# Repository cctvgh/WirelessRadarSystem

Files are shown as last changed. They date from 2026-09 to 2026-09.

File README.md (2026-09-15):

---
AIGC:
  ContentProducer: '001191110102MAD55U9H0F10002'
  ContentPropagator: '001191110102MAD55U9H0F10002'
  Label: '1'
  ProduceID: 'b8762ebd-76c9-41ca-a2bb-6e1f6f4c271a'
  PropagateID: 'b8762ebd-76c9-41ca-a2bb-6e1f6f4c271a'
  ReservedCode1: '906948f1-5d60-43a9-a1cf-7321b16a049e'
  ReservedCode2: '906948f1-5d60-43a9-a1cf-7321b16a049e'
---

# 无线毫米波雷达智能感知系统 V1.0（Wireless mmWave Radar Smart System）

基于 **24GHz 毫米波雷达（RD-03D）+ ESP32 无线节点**的室内目标感知系统。雷达节点通过 Wi-Fi 将探测目标无线传输至接收端，实现人-雷达-屏幕**零线缆分离部署**，具备警戒区告警、多节点组网、PC Web 可视化、轨迹记录与 CSV 导出等能力，附带**无硬件模拟器**。

> 本仓库是 [Arduino-ESP32-Radarproject](https://github.com/Stevee87/Arduino-ESP32-Radarproject)（MIT License, Copyright (c) 2026 Sudo_solder）的**深度二次开发作品**：在保留原始版权声明的前提下完成代码重构与原创功能增强。

## 功能特性

- **多目标追踪**：RD-03D 雷达最多同时追踪 3 个移动目标，探测距离 8 米、120° 视场
- **多节点组网**：UDP 协议支持最多 8 个雷达节点接入，节点独立分色显示
- **警戒区告警**：矩形警戒区实时判定，目标闯入触发告警（屏幕闪烁 + 蜂鸣 + 事件上报）
- **PC Web 可视化**：零依赖 Python 服务端 + 原生 HTML/Canvas 雷达界面，轨迹回放
- **数据导出**：一键导出 CSV（时间/节点/目标/坐标/速度），支持 Excel 二次分析
- **无硬件演示**：内置数据模拟器，秒级启动全链路演示
- **双端固件**：XIAO ESP32-S3 发射端 + Arduino GIGA R1 触摸屏接收端，随附 3D 打印外壳

## 快速开始（无硬件，1 分钟）

```powershell
cd server
python radar_server.py --simulate --web-port 8081
# 浏览器打开 http://127.0.0.1:8081/
```

有硬件（雷达+ESP32）请阅读 [references/hardware-guide.md](references/hardware-guide.md)。

## 系统架构

```
┌──────────────┐  UART 256000  ┌──────────────────┐  UDP 4210  ┌────────────────────┐
│ RD-03D 雷达  │◄─────────────►│ XIAO ESP32-S3 节点│ ─────────► │ 接收端（二选一）    │
│ 24GHz 多目标 │  帧解析/聚类   │ (发射端固件)      │  无线传输   │ Giga R1 屏显接收端   │
└──────────────┘               └──────────────────┘            │ 或 PC Web 可视化服务 │
                                                                 └────────────────────┘
```

## 目录结构

```
wireless-radar-system/
├── SKILL.md                  # TeleAgent 技能定义
├── LICENSE                   # MIT（含原作者声明）
├── firmware/                 # 双端固件（Arduino）
├── server/                   # PC 服务端 + Web 可视化
├── tools/                    # 无硬件数据模拟器
├── CAD/                      # 3D 打印外壳（4 个 STL）
└── references/               # 部署 / 硬件 / 协议文档
```

## 许可

MIT License — 二次开发声明详见 [LICENSE](LICENSE)。原始项目版权归 Sudo_solder 所有。

## 支持

- 问题反馈：GitHub Issues
- 部署指南：`references/deploy-guide.md`
- 数据协议：`references/protocol.md`

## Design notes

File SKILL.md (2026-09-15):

---
name: wireless-radar-system
description: Deploy and run the Wireless mmWave Radar Smart System - a 24GHz RD-03D mmWave radar (ESP32 wireless node) target sensing system with multi-node networking, alarm zones, PC Web visualization, track recording, CSV export and a no-hardware simulator. Trigger when the user wants to set up, run, or troubleshoot ESP32 radar deployment, millimeter-wave human detection, activity security sensing, or radar data visualization.
name_cn: 无线毫米波雷达智能感知系统
description_cn: 基于RD-03D 24GHz毫米波雷达与ESP32无线节点的目标感知系统，支持多节点组网、警戒区告警、PC Web可视化、轨迹记录与CSV导出，含无硬件模拟器，适用于活动保障安防、智能感知研究与教学演示
AIGC:
  ContentProducer: '001191110102MAD55U9H0F10002'
  ContentPropagator: '001191110102MAD55U9H0F10002'
  Label: '1'
  ProduceID: '391d303b-906a-4549-b1cc-22d6e3efd3d9'
  PropagateID: '391d303b-906a-4549-b1cc-22d6e3efd3d9'
  ReservedCode1: '5a9f9206-22fd-4a40-b052-a54a07ec6523'
  ReservedCode2: '5a9f9206-22fd-4a40-b052-a54a07ec6523'
---

# 无线毫米波雷达智能感知系统（Wireless mmWave Radar Smart System）

基于 **24GHz 毫米波雷达（RD-03D）+ ESP32 无线节点**的室内目标追踪与智能感知系统。雷达节点通过 Wi-Fi 将探测目标无线传输至接收端，实现 **人-雷达-屏幕零线缆分离部署**，并具备警戒区告警、多节点组网、轨迹记录等增强能力。

> 本技能是 [Arduino-ESP32-Radarproject](https://github.com/Stevee87/Arduino-ESP32-Radarproject)（MIT License, Copyright (c) 2026 Sudo_solder）的深度二次开发作品，新增 PC 可视化服务端、多节点组网、警戒告警、模拟器等功能，软著登记为独立开发。

---

## 适用场景

- **活动保障/安防值守**：大型活动现场人员进出探测、警戒区域闯入告警
- **无线感知研究**：毫米波雷达数据处理、多目标追踪算法验证
- **智能家居/办公**：人员存在感知、区域占用统计、自动联动
- **教学演示**：无硬件环境下使用内置模拟器演示雷达扫描界面

## 系统架构

```
┌──────────────┐  UART 256000  ┌──────────────────┐  UDP 4210  ┌────────────────────┐
│ RD-03D 雷达  │◄─────────────►│ XIAO ESP32-S3 节点│◄──────────►│ 接收端（二选一）    │
│ 24GHz 多目标 │  帧解析/聚类   │ (发射端固件)      │  无线传输   │ Giga R1 屏显接收端   │
└──────────────┘               └──────────────────┘            │ 或 PC Web 可视化服务 │
                                                                 └────────────────────┘
```

- **发射端**：XIAO ESP32-S3 读取 RD-03D 雷达帧，目标聚类后经 UDP 无线发送
- **接收端（Giga R1）**：自带触摸屏的移动显示单元，警戒告警 + 蜂鸣提示
- **接收端（PC 服务端）**：纯标准库 Python 服务，Web 可视化 + 轨迹记录 + CSV 导出 + 告警引擎
- **模拟器**：无硬件即可演示完整链路

## 使用方式

### 方式一：无硬件演示（最快上手）

```powershell
# 1. 启动 PC 服务端（内置模拟器）
cd wireless-radar-system\server
python radar_server.py --simulate --web-port 8081

# 2. 浏览器打开
http://127.0.0.1:8081/
```

### 方式二：独立模拟器（联调测试）

```powershell
python radar_server.py --web-port 8081          # 终端 A：启动服务端
python ..\tools\radar_simulator.py --nodes 2    # 终端 B：模拟节点发包
```

### 方式三：真实硬件（双端固件烧录）

1. 按 `references/hardware-guide.md` 准备物料并接线
2. Arduino IDE 打开 `firmware/rd03d_receiver/rd03d_receiver.ino`，烧录至 GIGA R1
   - 依赖库：`Arduino_GigaDisplay_GFX`、`Arduino_GigaDisplayTouch`
3. 打开 `firmware/rd03d_transmitter/rd03d_transmitter.ino`，烧录至 XIAO ESP32-S3
   - 核心库：`WiFi`、`WiFiUdp`（内置）
4. **上电顺序**：先给 GIGA R1 上电，待热点 `RadarNet` 出现后，再给雷达节点上电
5. 若要 PC 端同时查看，将 PC 接入同一热点后运行 `radar_server.py`

## 文件结构

```
wireless-radar-system/
├── SKILL.md                  # 本指南
├── LICENSE                   # MIT（含原作者声明）
├── firmware/
│   ├── rd03d_transmitter/    # 雷达节点发射端固件（ESP32-S3）
│   └── rd03d_receiver/       # 显示接收端固件（Giga R1）
├── server/
│   ├── radar_server.py       # PC 服务端（UDP+Web，纯标准库）
│   └── index.html            # Web 雷达可视化界面
├── tools/
│   └── radar_simulator.py    # 无硬件数据模拟器
└── references/
    ├── deploy-guide.md       # 部署指南（含 BAT 一键脚本）
    ├── hardware-guide.md     # 物料清单与接线图
    └── protocol.md           # RD-03D 数据协议与 UDP 报文格式
```

## 已知限制

- RD-03D 为多普勒雷达，仅能探测**移动目标**，静止站立人员不产生回波
- 24GHz 信号可穿透薄门/墙但探测距离显著衰减
- 默认 WiFi 凭据（`RadarNet`/`radar12345`）为局域网演示配置，正式部署请修改固件中的 `WIFI_SSID`/`WIFI_PASSWORD`
- GIGA R1 与雷达节点上电顺序有要求：先接收端后节点

## 协议与合规

- 本系统二次开发自 MIT 开源项目，保留原始版权声明，可自由使用、修改与分发
- 雷达模块按所在地区无线电管理要求使用（RD-03D 已取得 CE 认证）
- 本项目不含任何遥测、数据外传与后门代码（安全扫描零高风险项）

## 版本

- V1.0（2026-09）：首个正式版本，含双端固件、PC 可视化服务端、模拟器

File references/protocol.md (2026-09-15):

---
AIGC:
  ContentProducer: '001191110102MAD55U9H0F10002'
  ContentPropagator: '001191110102MAD55U9H0F10002'
  Label: '1'
  ProduceID: 'fb770e5b-8f00-4d1e-bbb1-88ac91fa3b59'
  PropagateID: 'fb770e5b-8f00-4d1e-bbb1-88ac91fa3b59'
  ReservedCode1: 'ccf5ac3a-8de8-4e19-a242-96e7e08e9d3e'
  ReservedCode2: 'ccf5ac3a-8de8-4e19-a242-96e7e08e9d3e'
---

# RD-03D 数据协议与 UDP 封包格式

本文件定义无线毫米波雷达智能感知系统 V1.0 的完整数据链路协议，供二次开发与排障参考。

## 1. RD-03D 雷达串口协议

RD-03D（Ai-Thinker，24GHz FMCW/多普勒毫米波雷达）通过 UART 输出目标数据帧，波特率 **256000**。

### 1.1 数据帧结构

| 段 | 长度 | 说明 |
|----|---|---|
| 帧头 | 4 字节 | `AA FF 03 00` |
| 载荷 | 26 字节 | 3 组目标数据（每组 8 字节）+ 2 字节尾校验 |
| 帧尾 | 2 字节 | `55 CC` |

### 1.2 单目标数据（8 字节）

| 偏移 | 长度 | 字段 | 说明 |
|---|---|---|---|
| 0-1 | 2B | X | 横向坐标（毫米），有符号 16 位补码 |
| 2-3 | 2B | Y | 纵向距离（毫米），有符号 16 位补码 |
| 4-5 | 2B | SPD | 速度（毫米/秒），有符号 |
| 6-7 | 2B | 预留 | 恒为 0 |

**空目标**：8 字节全零表示该目标槽无有效数据。

**解码规则**（与固件 `decodeSigned` 一致）：

```
raw = lo | (hi << 8)
value = raw & 0x8000 ? (int16_t)(raw | 0xFFFF0000) : (int16_t)raw   # 补码符号扩展
```

**坐标说明**：X 为水平偏移（左负右正），Y 为径向距离（正前方）。距离过滤：仅接受 **100mm < 距离 ≤ 8000mm** 的有效目标。

### 1.3 指令帧（配置雷达）

| 指令 | 内容 | 用途 |
|---|---|---|
| 启用 | `FD FC FB FA 04 00 FF 00 01 00 04 03 02 01` | 启用雷达 |
| 多目标 | `FD FC FB FA 02 00 90 00 04 03 02 01` | 进入多目标模式 |
| 结束 | `FD FC FB FA 02 00 FE 00 04 03 02 01` | 结束指令序列 |

发射端固件在启动时依次下发三条指令，此后每 60 秒重复下发一次，防止雷达退出多目标模式。

## 2. UDP 无线传输协议

### 2.1 网络拓扑

```
发射节点 (XIAO ESP32-S3)  ——WiFi客户端——►  接收端热点 (AP)
   UDP 发送端口 = 4210          ◄——网关 IP 推断——  SSID: RadarNet
                                  密码: radar12345
```

发射端作为 STA 连接接收端建立的 AP 热点，**接收端 IP 通过 DHCP 网关地址自动获取**（`WiFi.gatewayIP()`）。

### 2.2 数据包（41 字节, packed, little-endian）

```
偏移    类型      字段          说明
0      uint32    magic         协议魔数 0x0D03DA7A（校验用）
4      uint32    nodeId        节点编号（1 起，多节点组网区分）
8      uint32    frameCount    帧计数
12     uint32    uptimeMs      节点运行毫秒
16     int16     t0.x          目标0 X
18     int16     t0.y          目标0 Y
20     int16     t0.spd        目标0 速度
22     uint8     t0.valid      目标0 有效标记
23     int16     t1.x          目标1 X
25     int16     t1.y          目标1 Y
27     int16     t1.spd        目标1 速度
29     uint8     t1.valid      目标1 有效标记
30     int16     t2.x          目标2 X
32     int16     t2.y          目标2 Y
34     int16     t2.spd        目标2 速度
36     uint8     t2.valid      目标2 有效标记
37     uint8     flags         状态位（bit0=节点在线）
38-40  uint8[3]  reserved      预留
```

Python 端解包模板（与 `radar_server.py` 一致）：

```python
PACKET_FMT = "<IIIIhhhBhhhBhhhBB3s"
```

### 2.3 心跳机制

发射端在超过 2 秒无目标数据时发送 **心跳包**（目标全零、`flags=0x01`），使接收端能持续感知节点在线状态。接收端超过 3 秒未收到任何数据包即判定节点离线。

## 3. 警戒区判定

警戒区为雷达坐标系中的矩形区域（毫米）：

```
X ∈ [-4000, 4000]    （横向）
Y ∈ [200, 4000]     （纵向：200mm 起避免贴脸误报）
```

任一台法目标落入矩形即触发警戒告警；目标全部离开后告警复位。判定逻辑在 Giga 固件与 PC 服务端中一致实现，事件以 JSON 上报：

```json
{"event":"alarm_enter","node":1}
{"event":"alarm_exit","node":1}
{"event":"node_lost","node":2}
```

## 4. 自定义扩展指引

- 新增传感器类型：在 `Target` 结构后扩展字段，同步更新两端 `struct` 定义与大小校验
- 调整警戒区：修改 `ALARM_ZONE_*` 宏（固件）与 `ALARM_ZONE_*` 常量（server.py）
- 修改组网凭据：修改 `WIFI_SSID`/`WIFI_PASSWORD`（两端固件），并保持一致

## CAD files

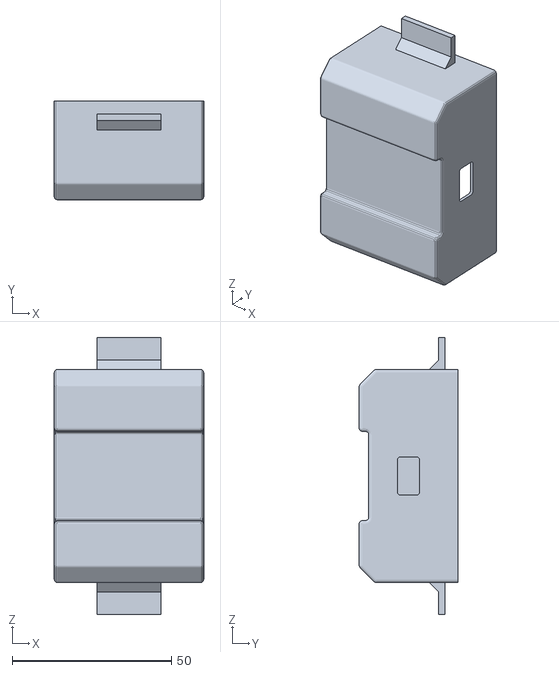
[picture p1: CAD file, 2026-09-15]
CAD/top radarmodule.stl
47.0 x 31.0 x 87.0

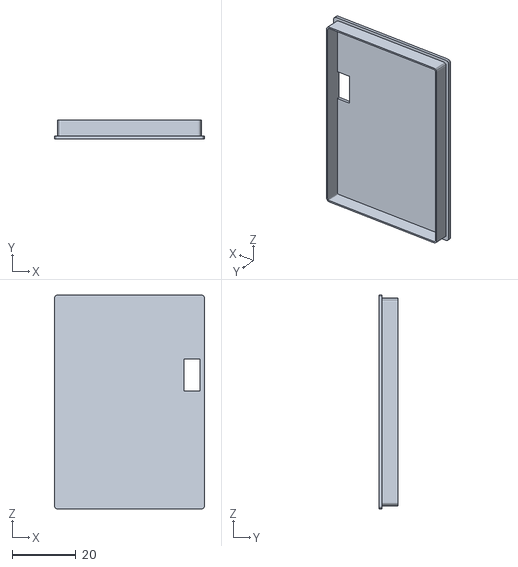
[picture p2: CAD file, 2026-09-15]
CAD/bottom radarmodule.stl
47.0 x 6.00 x 67.0

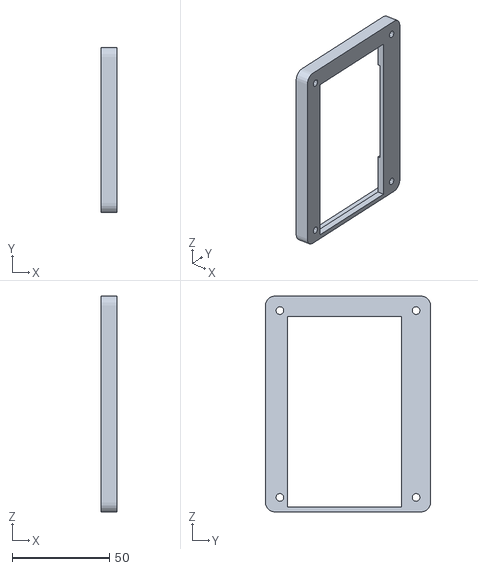
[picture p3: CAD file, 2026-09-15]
CAD/top display.stl
8.00 x 85.0 x 111.0

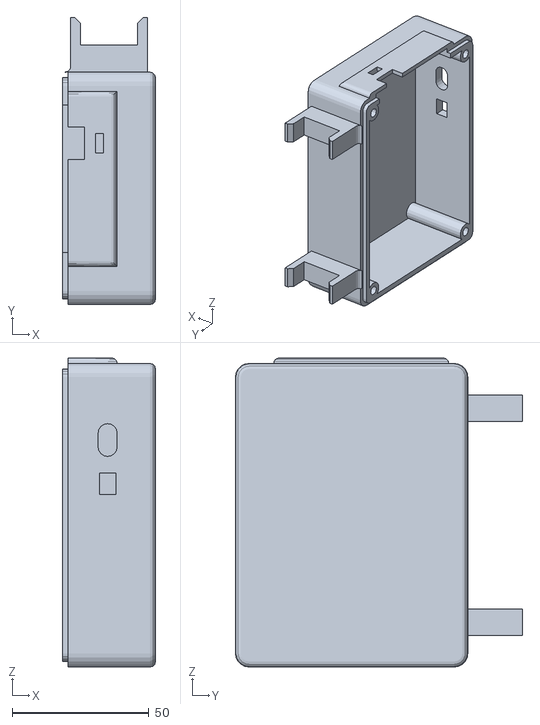
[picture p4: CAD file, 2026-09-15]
CAD/body display.stl
34.0 x 105.0 x 113.0

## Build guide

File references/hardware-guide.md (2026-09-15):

---
AIGC:
  ContentProducer: '001191110102MAD55U9H0F10002'
  ContentPropagator: '001191110102MAD55U9H0F10002'
  Label: '1'
  ProduceID: '7a103c28-e777-4f04-b889-d0c2404a3aee'
  PropagateID: '7a103c28-e777-4f04-b889-d0c2404a3aee'
  ReservedCode1: '4de7e3fe-066c-43c6-97f3-1e9d7269c627'
  ReservedCode2: '4de7e3fe-066c-43c6-97f3-1e9d7269c627'
---

# 硬件物料清单与接线指南

本文档为无线毫米波雷达智能感知系统 V1.0 的完整硬件部署说明。系统分为两个节点：

- **雷达节点（发射端）**：XIAO ESP32-S3 + RD-03D 雷达，电池供电，无线发射目标数据
- **显示节点（接收端）**：Arduino GIGA R1 + 显示扩展板，或 PC 运行服务端

## 1. 物料清单

### 雷达节点（发射端）

| 数量 | 物料 | 说明 |
|---|---|---|
| 1 | Seeed Studio XIAO ESP32-S3 | 主控，WiFi/BLE 双模 |
| 1 | RD-03D 雷达模块（安信可） | 24GHz 毫米波，3 目标，8m 探测 |
| 1 | 3.7V 锂聚合物电池 602560（约 1300mAh） | 雷达侧供电 |
| 1 | 拨动开关 | 电源开关 |
| 1 | MT3608 升压模块 | 3.7V → 5V 供雷达 |
| 若干 | 杜邦线/焊接线 | 连接线 |

> 雷达节点可直接用 XIAO 的 USB-C 充电，无需额外充电板。

### 显示节点（接收端，Giga R1 方案）

| 数量 | 物料 | 说明 |
|---|---|---|
| 1 | Arduino GIGA R1 | 主控，自带 WiFi（R4 无线模组） |
| 1 | GIGA Display Shield | 3.97 寸触摸屏 800x480 |
| 1 | 3.7V 锂电 1160100 ≥ 5000mAh | 显示侧供电 |
| 1 | 开关 | 电源开关 |
| 1 | MT3608 升压模块 | 3.7V → 6V 供 GIGA VIN |
| 1 | BW4056 USB-C 充电板 | 显示侧充电 |
| 1 | 无源压电蜂鸣器模块 | 距离感知/告警提示音 |
| 1 | Mini 电量指示板（1S Li-ion） | 电池电量显示（可选） |

## 2. 接线说明

### 2.1 雷达节点接线（XIAO ESP32-S3 ↔ RD-03D）

| RD-03D | XIAO ESP32-S3 | 说明 |
|---|---|---|
| TX | D0（GPIO1） | UART1 RX（波特率 256000） |
| RX | D1（GPIO2） | UART1 TX |
| VCC | 5V | 由升压模块供电 |
| GND | GND | 共地 |

> **警告**：不要使用 D6/D7（GPIO43/44），它们被 USB-Serial（UART0）占用。

雷达节点供电链路：`锂电池 → 开关 → MT3608(5V) → XIAO 5V 与雷达 VCC`。

### 2.2 显示节点供电

Giga R1 侧：`LiPo(5000mAh) → 开关 → 升压(6V) → GIGA VIN`。

### 2.3 蜂鸣器接线（显示节点）

| 蜂鸣器 | GIGA R1 |
|---|---|
| VCC | 5V |
| Signal | D9 |
| GND | GND |

> 必须使用 **无源** 压电蜂鸣器。有源蜂鸣器自带振荡器，无法响应固件发送的频率参数。

### 2.4 网络参数（默认值）

| 参数 | 值 |
|---|-----|
| AP SSID | `RadarNet` |
| AP 密码 | `radar12345` |
| UDP 端口 | `4210` |
| GIGA IP | `192.168.4.1`（AP 网关） |

## 3. 固件烧录

### 3.1 安装 Arduino IDE 依赖

**显示节点（Giga R1）**：
1. 开发板管理器安装 `Arduino Mbed OS GIGA Boards`
2. 库管理器安装 `Arduino_GigaDisplay_GFX`、`Arduino_GigaDisplayTouch`

**雷达节点（XIAO ESP32-S3）**：
1. 开发板管理器安装 `esp32`（Espressif）
2. 选择板型 `XIAO ESP32-S3`（Seeed 支持包）

### 3.2 烧录步骤

```
1. 打开 firmware/rd03d_receiver/rd03d_receiver.ino，烧录到 GIGA R1
2. 打开 firmware/rd03d_transmitter/rd03d_transmitter.ino，烧录到 XIAO ESP32-S3
3. 若 XIAO 为全新板，需先按住 BOOT 键插入 USB 进入下载模式
```

### 3.3 上电顺序（关键）

1. **先给 GIGA R1 上电**，等待热点 `RadarNet` 出现（约 8 秒）
2. 再给雷达节点上电，节点自动连接热点并开始上报

> 顺序颠倒会导致 Wi-Fi 连接失败，需重启节点。

## 4. 3D 打印外壳

原项目提供 4 个 STL 文件（位于原始仓库 `CAD files/`，本技能发布包已包含）：

| 文件 | 尺寸 (W×D×H) | 用途 |
|---|---|---|
| `body display.stl` | 31 × 83 × 109 mm | 显示端机身 |
| `top display.stl` | — | 显示端顶盖 |
| `bottom radarmodule.stl` | 29 × 67 × 30 mm | 雷达端底壳 |
| `top radarmodule.stl` | 29 × 64 × 27 mm | 雷达端顶盖 |

## 5. 安全注意事项

- 锂电池接线务必核对极性，充电时关闭电源开关，充电过程有人值守
- 24GHz 频段按所在地无线电管理要求使用（RD-03D 已取得 CE 认证）
- 雷达可穿透薄墙/门探测运动目标，部署时注意隐私边界
- 本项目按 MIT 许可提供，无任何明示或默示担保，风险自担

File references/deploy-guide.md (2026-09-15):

---
AIGC:
  ContentProducer: '001191110102MAD55U9H0F10002'
  ContentPropagator: '001191110102MAD55U9H0F10002'
  Label: '1'
  ProduceID: '3113197a-09b9-4b55-b35b-a33c7c303491'
  PropagateID: '3113197a-09b9-4b55-b35b-a33c7c303491'
  ReservedCode1: 'ce95500b-d343-4c40-bd1f-807c65dc4cb3'
  ReservedCode2: 'ce95500b-d343-4c40-bd1f-807c65dc4cb3'
---

# 部署指南

本文档覆盖三种部署形态：**纯 PC 演示**（无硬件）、**硬件双节点**、**PC 接收端与硬件共存**，并提供一键启动脚本。

## 1. 环境要求

| 项 | 要求 |
|----|---|
| Python | 3.8+（Windows/Linux/macOS 均可） |
| 依赖 | **零第三方依赖**（仅标准库） |
| 浏览器 | Chrome / Edge / Firefox（支持 Canvas 与 Fetch） |
| 硬件（可选） | XIAO ESP32-S3 + RD-03D、Arduino GIGA R1（需烧录固件） |

> 无 Python 环境时也可直接双击 `server/index.html` 查看界面，但无实时数据。

## 2. 方式一：纯 PC 演示（无需任何硬件）

### 2.1 启动服务端（内置模拟器）

```powershell
cd wireless-radar-system\server
python radar_server.py --simulate --web-port 8081
```

启动后终端显示：

```
============================================================
 无线毫米波雷达智能感知系统 V1.0 - PC 服务端
============================================================
 UDP 监听端口 : 4210
 Web 界面     : http://127.0.0.1:8081/
```

### 2.2 访问可视化界面

浏览器打开 `http://127.0.0.1:8081/`，可看到：

- 雷达扫描动画、120° 视场、距离圈（0.5m–8m）
- 2 个模拟节点、4 个运动目标及轨迹
- 警戒区（黄色虚线矩形）与目标闯入告警（红色横幅 + 蜂鸣）
- 节点状态、目标数、帧率实时统计
- 「导出 CSV」下载全部轨迹数据

## 3. 方式二：有硬件双节点部署

### 3.1 烧录固件

按 `references/hardware-guide.md` 完成接线与烧录。

### 3.2 上电

1. 先给 GIGA R1（接收端）上电，等待热点 `RadarNet` 出现
2. 再给 XIAO ESP32-S3（雷达节点）上电，节点自动连接并上报
3. GIGA 触摸屏显示雷达界面，默认蜂鸣器开启，点击「BUZZER AN」静音

### 3.3 可选：PC 接收

若希望 PC 端同时接收与记录，将 PC 接入同一 WiFi（`RadarNet`），然后：

```powershell
python radar_server.py --web-port 8081
```

PC 通过热点直接接收节点 UDP 数据（默认端口 4210）。

## 4. 方式三：独立模拟器联调

终端 A（服务端）与终端 B（模拟器）分开运行：

```powershell
# 终端 A
python radar_server.py --web-port 8081

# 终端 B
python ..\tools\radar_simulator.py --host 127.0.0.1 --port 4210 --nodes 2 --targets 3
```

模拟器参数：

| 参数 | 默认 | 说明 |
|---|---|---|
| `--host` | 127.0.0.1 | 服务端 IP |
| `--port` | 4210 | UDP 端口 |
| `--nodes` | 2 | 模拟节点数（1-8） |
| `--targets` | 2 | 每节点活动目标数 |
| `--fps` | 10 | 发送帧率 |

## 5. 一键启动脚本（Windows）

创建 `启动雷达演示.bat`（UTF-8 编码）到项目根目录：

```bat
@echo off
chcp 65001 >nul
title 无线毫米波雷达智能感知系统
cd /d "%~dp0server"
start "radar-server" python radar_server.py --simulate --web-port 8081
timeout /t 5 >nul
start "" "http://127.0.0.1:8081/"
echo 雷达演示已启动，浏览器自动打开...
pause
```

停止脚本 `停止雷达.bat`：

```bat
@echo off
taskkill /IM python.exe /FI "WINDOWTITLE eq radar-server" /T /F >nul 2>&1
echo 已停止
pause
```

## 6. 常见问题

| 现象 | 排查 |
|---|---|
| Web 页面打不开 | 确认服务端已启动；检查端口是否被占用（`netstat -ano | findstr 8081`） |
| 界面无目标数据 | 确认模拟器/节点已发送数据；检查 UDP 端口一致 |
| 节点状态一直「离线」 | 检查节点 WiFi 连接、热点 SSID/密码、上电顺序 |
| 告警不触发 | 确认警戒区参数与目标坐标；模拟目标是否进入 `Y≥200` 区域 |
| 8080 被占用 | 加 `--web-port` 改用其他端口（如 8081） |

## 7. 数据导出

「导出CSV」生成文件包含列：

```
ts,node,target,x_mm,y_mm,speed_mm_s,distance_mm
```

可用于 Excel 二次分析（进入/离开次数、逗留时长、热力统计）。

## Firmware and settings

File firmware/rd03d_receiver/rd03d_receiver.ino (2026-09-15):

/*
 * ============================================================================
 *  无线毫米波雷达智能感知系统 V1.0 —— 雷达显示接收端固件（Arduino Giga R1）
 *  Wireless mmWave Radar Smart System - Radar Display Receiver Firmware
 * ============================================================================
 *  硬件平台  : Arduino GIGA R1 + GIGA Display Shield（800x480 触摸屏）
 *  功能概述  :
 *    1. 建立 WiFi 热点（默认 SSID=RadarNet），供雷达节点接入
 *    2. UDP 接收多节点雷达数据（协议魔数校验，按 nodeId 区分节点）
 *    3. 雷达扫描界面实时渲染：扇形扫描、距离圈、目标点（多节点分色）
 *    4. 目标"幽灵"过滤：2 秒无真实位移的目标自动隐藏，抑制静止杂波
 *    5. 警戒区域告警：目标进入配置的警戒区触发报警（蜂鸣器+屏显+串口事件）
 *    6. 距离感知蜂鸣：无源压电蜂鸣器按最近目标距离缩放节拍与音调
 *    7. 触摸静音按钮：一键关闭蜂鸣器，不影响雷达可视化
 *    8. 连接状态看门狗：节点失联自动清理显示并提示
 *  网络参数  : AP SSID=RadarNet / 密码=radar12345 / UDP 端口=4210 / 自身 IP=192.168.4.1
 *  蜂鸣器    : 无源压电蜂鸣器 VCC=5V / Signal=D9 / GND=GND
 *  参考来源  : Arduino-ESP32-Radarproject (MIT License, Copyright (c) 2026 Sudo_solder)
 *              本固件在 MIT 许可下深度重构并增强功能。
 * ============================================================================
 *  MIT License - 详见项目根目录 LICENSE
 * ============================================================================
 */

#include <WiFi.h>
#include <WiFiUDP.h>
#include "Arduino_GigaDisplay_GFX.h"
#include "Arduino_GigaDisplayTouch.h"

/* ============================ 集中配置区 ============================ */

// ---- 网络配置（热点）----
#define AP_SSID        "RadarNet"        // 热点名称
#define AP_PASS        "radar12345"     // 热点密码
#define UDP_PORT       4210             // UDP 监听端口
#define MAX_NODES      4                // 最大支持节点数（多节点组网）

// ---- 显示与雷达 ----
#define SCREEN_W       800
#define SCREEN_H       480
#define RADAR_CX       400
#define RADAR_CY       480
#define RADAR_R        440
#define MAX_DIST_MM    8000.0f
#define SECTOR_HALF    60.0f
#define MAX_TARGETS    3               // 单节点最多 3 目标
#define MOVE_THRESH_MM 15.0f           // 目标位移判定阈值（毫米）

// ---- 警戒区配置（雷达坐标系，单位毫米）----
#define ALARM_ZONE_MIN_X  -4000        // 警戒区 X 下限
#define ALARM_ZONE_MAX_X   4000        // 警戒区 X 上限
#define ALARM_ZONE_MIN_Y  200          // 警戒区 Y 下限（近处）
#define ALARM_ZONE_MAX_Y  4000         // 警戒区 Y 上限（远处）

// ---- 蜂鸣器 ----
#define BUZZER_PIN       9             // 无源蜂鸣器信号引脚
#define BEEP_DUR_MS      70            // 单个蜂鸣时长
#define BEEP_DIST_MIN    300.0f        // 最近距离（毫米）
#define BEEP_DIST_MAX    8000.0f       // 最远距离（毫米）
#define BEEP_INTERVAL_MIN  120         // 最近蜂鸣间隔（毫秒）
#define BEEP_INTERVAL_MAX  900         // 最远蜂鸣间隔（毫秒）
#define BEEP_FREQ_MIN      700         // 最远音调（Hz）
#define BEEP_FREQ_MAX      1800        // 最近音调（Hz）
#define ALARM_FREQ         2200        // 警戒告警音调（Hz）
#define ALARM_INTERVAL_MS  250         // 警戒告警间隔（毫秒）

// ---- 静音按钮 ----
#define BTN_X 671
#define BTN_Y 80
#define BTN_W 128
#define BTN_H 40

// ---- 连接看门狗 ----
#define LINK_TIMEOUT_MS     3000        // 节点失联判定时间
#define BG_REFRESH_INTERVAL_MS 10000    // 全屏刷新周期（消除残影）
#define STILL_TIMEOUT_MS    2000        // 幽灵目标静止隐藏时间

/* ============================ 数据结构 ============================ */

// 单目标
struct Target {
  int16_t x;        // X 坐标（毫米）
  int16_t y;        // Y 坐标（毫米）
  int16_t spd;      // 速度（毫米/秒）
  uint8_t valid;    // 有效性
};

// 网络数据包（与发射端保持一致）
struct __attribute__((packed)) UdpPacket {
  uint32_t magic;       // 协议魔数 0xD03DA7A
  uint32_t nodeId;      // 节点编号
  uint32_t frameCount;  // 帧计数
  uint32_t uptimeMs;    // 节点运行时间
  Target   targets[MAX_TARGETS];
  uint8_t  flags;       // 状态位
  uint8_t  reserved[3];
};

// 显示目标
struct DisplayTarget {
  float x, y, spd;
  bool  valid;
  bool  inAlarmZone;    // 是否处于警戒区
};

// 节点状态
struct NodeState {
  bool     online;
  uint32_t lastPacketMs;
  uint32_t lastFrame;
  uint32_t nodeId;
};

// 目标点渲染状态
struct DotState {
  int16_t cx, cy, bx, by, bw, bh;
  bool active;
};

/* ============================ 全局变量 ============================ */

GigaDisplay_GFX          display;
Arduino_GigaDisplayTouch touch;
WiFiUDP                  udp;

NodeState     nodes[MAX_NODES];
DisplayTarget targets[MAX_NODES][MAX_TARGETS];
DisplayTarget lastDrawn[MAX_NODES][MAX_TARGETS];
DotState      dots[MAX_NODES][MAX_TARGETS];
DisplayTarget prevRaw[MAX_NODES][MAX_TARGETS];      // 幽灵过滤基准
uint32_t      stillSinceMs[MAX_NODES][MAX_TARGETS];
bool          staleNow[MAX_NODES][MAX_TARGETS];

uint32_t frameCountGlobal = 0;
bool     alarmActive      = false;   // 当前帧是否处于警戒告警
bool     alarmWasActive   = false;   // 上一帧警戒状态（用于事件沿触发）
bool     buzzerMuted      = false;

uint32_t lastBeepMs   = 0;
bool     beepActive   = false;
uint32_t beepStartMs  = 0;

bool     touchDownLast = false;
uint32_t lastToggleMs  = 0;

uint32_t lastBgRefreshMs = 0;
uint32_t lastUptimeMs    = 0;

/* ============================ 颜色定义 ============================ */

#define C_BG     0x0000
#define C_GREEN  0x07E0
#define C_GDIM   0x02E0
#define C_RED    0xF800
#define C_AMBER  0xFD20
#define C_CYAN   0x07FF
#define C_WHITE  0xFFFF
#define C_ORANGE 0xFBE0

// 节点颜色（最多 4 节点）
static const uint16_t NODE_COLS[4] = {C_RED, C_AMBER, C_CYAN, C_ORANGE};

/* ============================ 函数声明 ============================ */

bool inAlarmZone(float x, float y);

/* ============================ UDP 接收 ============================ */

/**
 * @brief 接收并解析节点 UDP 数据包
 *        校验魔数后按 nodeId 路由到对应节点的状态槽，更新目标数据
 */
void receiveUdp() {
  int sz = udp.parsePacket();
  if (sz < (int)sizeof(UdpPacket)) return;

  UdpPacket pkt;
  udp.read((uint8_t*)&pkt, sizeof(pkt));

  // 协议魔数校验
  if (pkt.magic != 0xD03DA7A) return;

  // 节点索引（nodeId 从 1 开始）
  int idx = (int)(pkt.nodeId - 1);
  if (idx < 0 || idx >= MAX_NODES) idx = 0;

  nodes[idx].online       = true;
  nodes[idx].lastPacketMs = millis();
  nodes[idx].lastFrame    = pkt.frameCount;
  nodes[idx].nodeId       = pkt.nodeId;

  frameCountGlobal = pkt.frameCount;

  // 更新目标数据
  for (int t = 0; t < MAX_TARGETS; t++) {
    if (pkt.targets[t].valid) {
      targets[idx][t].x     = (float)pkt.targets[t].x;
      targets[idx][t].y     = (float)pkt.targets[t].y;
      targets[idx][t].spd   = (float)abs(pkt.targets[t].spd);
      targets[idx][t].valid = true;
      targets[idx][t].inAlarmZone = inAlarmZone((float)pkt.targets[t].x, (float)pkt.targets[t].y);
    } else {
      targets[idx][t].valid = false;
    }
  }
}

/**
 * @brief 警戒区判定：目标坐标是否落入警戒矩形
 */
bool inAlarmZone(float x, float y) {
  return (x >= ALARM_ZONE_MIN_X && x <= ALARM_ZONE_MAX_X &&
          y >= ALARM_ZONE_MIN_Y && y <= ALARM_ZONE_MAX_Y);
}

/* ============================ 坐标变换与背景 ============================ */

/**
 * @brief 距离到像素半径的非线性映射（近处放大、远处压缩）
 */
float distToR(float d) {
  if (d <= 0)       return 0;
  if (d <= 2000.0f) return (d / 2000.0f) * 0.50f * RADAR_R;
  if (d <= 4000.0f) return (0.50f + (d - 2000.0f) / 2000.0f * 0.25f) * RADAR_R;
  if (d <= 6000.0f) return (0.75f + (d - 4000.0f) / 2000.0f * 0.15f) * RADAR_R;
  return (0.90f + (d - 6000.0f) / 2000.0f * 0.10f) * RADAR_R;
}

void targetToPixel(float x, float y, int16_t &px, int16_t &py) {
  float dist  = sqrtf(x * x + y * y);
  float angle = atan2f(x, y) * 180.0f / PI;
  float r     = distToR(dist);
  float rad   = (angle - 90.0f) * PI / 180.0f;
  px = RADAR_CX + (int16_t)(r * cosf(rad));
  py = RADAR_CY + (int16_t)(r * sinf(rad));
}

/**
 * @brief 在雷达界面上绘制警戒区轮廓（黄色矩形 + ZONE 标注）
 */
void drawAlarmZoneOutline() {
  int16_t x1, y1, x2, y2;
  targetToPixel(ALARM_ZONE_MIN_X, ALARM_ZONE_MIN_Y, x1, y1);
  targetToPixel(ALARM_ZONE_MAX_X, ALARM_ZONE_MAX_Y, x2, y2);
  display.drawRect(min(x1, x2), min(y1, y2), abs(x2 - x1), abs(y2 - y1), C_AMBER);
  display.setTextColor(C_AMBER); display.setTextSize(1);
  display.setCursor(min(x1, x2) + 2, min(y1, y2) + 2);
  display.print("ZONE");
}

/**
 * @brief 重绘指定矩形区域内的背景（用于目标点擦除，避免整体闪烁）
 */
void redrawBg(int16_t rx1, int16_t ry1, int16_t rw, int16_t rh) {
  int16_t rx2 = rx1 + rw - 1, ry2 = ry1 + rh - 1;
  if (rx1 < 0) rx1 = 0; if (ry1 < 0) ry1 = 0;
  if (rx2 >= SCREEN_W) rx2 = SCREEN_W - 1;
  if (ry2 >= SCREEN_H) ry2 = SCREEN_H - 1;
  if (rx1 > rx2 || ry1 > ry2) return;
  display.fillRect(rx1, ry1, rx2 - rx1 + 1, ry2 - ry1 + 1, C_BG);

  // 扇形扫描网格（单传感器 120° 视场，居中于 0°）
  float c = 0.0f;
  for (float a = c - SECTOR_HALF; a <= c + SECTOR_HALF; a += 0.6f) {
    float rad = (a - 90.0f) * PI / 180.0f;
    for (float r = 0; r <= RADAR_R; r += 1.5f) {
      int16_t px = RADAR_CX + (int16_t)(r * cosf(rad));
      int16_t py = RADAR_CY + (int16_t)(r * sinf(rad));
      if (px >= rx1 && px <= rx2 && py >= ry1 && py <= ry2) display.drawPixel(px, py, 0x0180);
    }
  }

  // 距离圈（0.5m~8m）
  float rd[] = {500, 1000, 2000, 3000, 4000, 5000, 6000, 7000, 8000};
  uint16_t rc[] = {0x00C0, C_GREEN, 0x00C0, 0x00C0, C_GDIM, 0x00C0, 0x00C0, 0x00C0, C_GREEN};
  for (int ri = 0; ri < 9; ri++) {
    float r = distToR(rd[ri]);
    for (float a = c - SECTOR_HALF; a <= c + SECTOR_HALF; a += 0.5f) {
      float rad = (a - 90.0f) * PI / 180.0f;
      int16_t px = RADAR_CX + (int16_t)(r * cosf(rad));
      int16_t py = RADAR_CY + (int16_t)(r * sinf(rad));
      if (px >= rx1 && px <= rx2 && py >= ry1 && py <= ry2) display.drawPixel(px, py, rc[ri]);
    }
  }

  // 角度线
  int degs[] = {-60, -30, 0, 30, 60};
  for (int i = 0; i < 5; i++) {
    float rad = (c + degs[i] - 90.0f) * PI / 180.0f;
    for (float r = 0; r <= RADAR_R; r += 1.5f) {
      int16_t px = RADAR_CX + (int16_t)(r * cosf(rad));
      int16_t py = RADAR_CY + (int16_t)(r * sinf(rad));
      if (px >= rx1 && px <= rx2 && py >= ry1 && py <= ry2)
        display.drawPixel(px, py, degs[i] == 0 ? C_GDIM : 0x0200);
    }
  }

  // 警戒区轮廓
  drawAlarmZoneOutline();

  // 雷达原点
  if (RADAR_CX >= rx1 && RADAR_CX <= rx2 && RADAR_CY >= ry1 && RADAR_CY <= ry2) {
    display.fillCircle(RADAR_CX, RADAR_CY, 5, C_GREEN);
    display.drawCircle(RADAR_CX, RADAR_CY, 9, C_GDIM);
  }
}

/**
 * @brief 全屏绘制雷达背景
 */
void drawBackground() {
  display.fillScreen(C_BG);
  float c = 0.0f;

  // 扇形网格
  for (float a = c - SECTOR_HALF; a <= c + SECTOR_HALF; a += 0.6f) {
    float rad = (a - 90.0f) * PI / 180.0f;
    for (float r = 0; r <= RADAR_R; r += 1.5f) {
      int16_t px = RADAR_CX + (int16_t)(r * cosf(rad));
      int16_t py = RADAR_CY + (int16_t)(r * sinf(rad));
      if (px >= 0 && px < SCREEN_W && py >= 0 && py < SCREEN_H) display.drawPixel(px, py, 0x0180);
    }
  }

  // 距离圈与标注
  float rd[] = {500, 1000, 2000, 3000, 4000, 5000, 6000, 7000, 8000};
  uint16_t rc[] = {0x00C0, C_GREEN, 0x00C0, 0x00C0, C_GDIM, 0x00C0, 0x00C0, 0x00C0, C_GREEN};
  for (int ri = 0; ri < 9; ri++) {
    float r = distToR(rd[ri]);
    for (float a = c - SECTOR_HALF; a <= c + SECTOR_HALF; a += 0.5f) {
      float rad = (a - 90.0f) * PI / 180.0f;
      int16_t px = RADAR_CX + (int16_t)(r * cosf(rad));
      int16_t py = RADAR_CY + (int16_t)(r * sinf(rad));
      if (px >= 0 && px < SCREEN_W && py >= 0 && py < SCREEN_H) display.drawPixel(px, py, rc[ri]);
    }
    display.setTextColor(ri == 1 || ri == 8 ? C_GREEN : 0x0380); display.setTextSize(1);
    char buf[8];
    if (rd[ri] < 1000) sprintf(buf, "0.5m"); else sprintf(buf, "%.0fm", rd[ri] / 1000.0f);
    float rR = (c + SECTOR_HALF - 90.0f) * PI / 180.0f;
    int16_t lx = RADAR_CX + (int16_t)((r + 4) * cosf(rR)) + 2;
    int16_t ly = RADAR_CY + (int16_t)((r + 4) * sinf(rR)) - 4;
    if (lx >= 0 && lx < SCREEN_W && ly >= 0 && ly < SCREEN_H) { display.setCursor(lx, ly); display.print(buf); }
  }

  // 边界线与角度线
  float radL = (c - SECTOR_HALF - 90.0f) * PI / 180.0f;
  float radR = (c + SECTOR_HALF - 90.0f) * PI / 180.0f;
  display.drawLine(RADAR_CX, RADAR_CY, RADAR_CX + (int16_t)(RADAR_R * cosf(radL)), RADAR_CY + (int16_t)(RADAR_R * sinf(radL)), C_GREEN);
  display.drawLine(RADAR_CX, RADAR_CY, RADAR_CX + (int16_t)(RADAR_R * cosf(radR)), RADAR_CY + (int16_t)(RADAR_R * sinf(radR)), C_GREEN);

  int degs[] = {-60, -30, 0, 30, 60};
  for (int i = 0; i < 5; i++) {
    float rad = (c + degs[i] - 90.0f) * PI / 180.0f;
    display.drawLine(RADAR_CX, RADAR_CY, RADAR_CX + (int16_t)(RADAR_R * cosf(rad)), RADAR_CY + (int16_t)(RADAR_R * sinf(rad)), degs[i] == 0 ? C_GDIM : 0x0260);
    char buf[5]; sprintf(buf, "%d", (int)(c + degs[i]));
    float lr = RADAR_R + 14.0f;
    int16_t lx = RADAR_CX + (int16_t)(lr * cosf(rad)) - 6;
    int16_t ly = RADAR_CY + (int16_t)(lr * sinf(rad)) - 4;
    if (lx >= 0 && lx < SCREEN_W && ly >= 0) { display.setTextColor(degs[i] == 0 ? C_GREEN : 0x0380); display.setTextSize(1); display.setCursor(lx, ly); display.print(buf); }
  }

  display.fillCircle(RADAR_CX, RADAR_CY, 5, C_GREEN);
  display.drawCircle(RADAR_CX, RADAR_CY, 9, C_GDIM);

  drawAlarmZoneOutline();

  // 信息框
  display.fillRect(670, 0, 130, 70, 0x0820);
  display.setTextColor(C_GDIM); display.setTextSize(1);
  display.setCursor(675, 4);  display.print("RD-03D 24GHz");
  display.setCursor(675, 14); display.print("3T 8m 120deg");
  display.setCursor(675, 24); display.print("AP: "); display.print(AP_SSID);
}

/* ============================ 目标渲染 ============================ */

void eraseDot(int ni, int ti) {
  if (!dots[ni][ti].active) return;
  redrawBg(dots[ni][ti].bx, dots[ni][ti].by, dots[ni][ti].bw, dots[ni][ti].bh);
  dots[ni][ti].active = false;
}

void drawDot(int ni, int ti) {
  int16_t tx, ty;
  targetToPixel(targets[ni][ti].x, targets[ni][ti].y, tx, ty);
  uint16_t col = NODE_COLS[ni % 4];

  // 警戒区内目标红色闪烁
  bool inZone = targets[ni][ti].inAlarmZone;
  if (inZone) col = ((millis() / 300) % 2 == 0) ? C_RED : C_WHITE;

  int16_t bx = tx - 20, by = ty - 20, bw = 112, bh = 44;
  display.drawCircle(tx, ty, 18, col);
  display.drawCircle(tx, ty, 11, col);
  display.fillCircle(tx, ty, 5, col);
  display.setTextColor(C_WHITE); display.setTextSize(1);
  float dist = sqrtf(targets[ni][ti].x * targets[ni][ti].x + targets[ni][ti].y * targets[ni][ti].y);
  char buf[14]; sprintf(buf, "%.2fm", dist / 1000.0f);
  display.setCursor(tx + 21, ty - 8); display.print(buf);
  if (targets[ni][ti].spd > 2.0f) {
    char sb[14]; sprintf(sb, "%dcm/s", (int)targets[ni][ti].spd);
    display.setCursor(tx + 21, ty + 4); display.print(sb);
  }
  if (inZone) {
    display.setTextColor(C_RED);
    display.setCursor(tx + 21, ty + 16); display.print("ZONE!");
  }
  dots[ni][ti] = {tx, ty, bx, by, bw, bh, true};
  lastDrawn[ni][ti] = targets[ni][ti];
}

/**
 * @brief 更新所有目标点显示（幽灵过滤、位移阈值、警戒告警判定与事件上报）
 */
void updateDots() {
  uint32_t now = millis();
  bool anyAlarm = false;

  for (int n = 0; n < MAX_NODES; n++) {
    for (int t = 0; t < MAX_TARGETS; t++) {
      staleNow[n][t] = false;
      if (!targets[n][t].valid) {
        stillSinceMs[n][t] = 0;
        prevRaw[n][t].valid = false;
        if (dots[n][t].active) eraseDot(n, t);
        continue;
      }

      // 真实位移判定（独立于渲染状态）
      bool movedRaw = !prevRaw[n][t].valid ||
                      fabsf(targets[n][t].x - prevRaw[n][t].x) > MOVE_THRESH_MM ||
                      fabsf(targets[n][t].y - prevRaw[n][t].y) > MOVE_THRESH_MM;
      if (movedRaw) stillSinceMs[n][t] = now;
      prevRaw[n][t] = targets[n][t];

      // 幽灵过滤：静止超过 2s 隐藏
      bool stale = (now - stillSinceMs[n][t]) > STILL_TIMEOUT_MS;
      staleNow[n][t] = stale;
      if (stale) {
        if (dots[n][t].active) eraseDot(n, t);
        continue;
      }

      // 警戒区触发
      if (targets[n][t].inAlarmZone) anyAlarm = true;

      // 位移超过阈值时重绘
      bool moved = fabsf(targets[n][t].x - lastDrawn[n][t].x) > MOVE_THRESH_MM ||
                   fabsf(targets[n][t].y - lastDrawn[n][t].y) > MOVE_THRESH_MM;
      if (dots[n][t].active && !moved && !targets[n][t].inAlarmZone) continue;
      if (dots[n][t].active) eraseDot(n, t);
      drawDot(n, t);
    }
  }

  // 警戒状态事件上报（串口 JSON，供上位机采集）
  if (anyAlarm && !alarmWasActive) {
    Serial.println("{\"event\":\"alarm_enter\"}");
  } else if (!anyAlarm && alarmWasActive) {
    Serial.println("{\"event\":\"alarm_exit\"}");
  }
  alarmWasActive = anyAlarm;
  alarmActive    = anyAlarm;

  updateInfoBox();
}

/**
 * @brief 更新信息框：在线节点、目标数、帧计数、警戒状态与节点状态灯
 */
void updateInfoBox() {
  display.fillRect(671, 34, 128, 36, 0x0820);
  display.setTextColor(C_GDIM); display.setTextSize(1);

  int online = 0;
  for (int n = 0; n < MAX_NODES; n++) if (nodes[n].online) online++;
  display.setCursor(675, 36);
  display.print("Node:"); display.print(online);

  int cnt = 0;
  for (int n = 0; n < MAX_NODES; n++)
    for (int t = 0; t < MAX_TARGETS; t++)
      if (targets[n][t].valid && !staleNow[n][t]) cnt++;
  display.print(" T:"); display.print(cnt);
  display.print(" fr:"); display.print(frameCountGlobal);

  display.setTextColor(alarmActive ? C_RED : C_GDIM);
  display.setCursor(675, 48);
  display.print(alarmActive ? "ALARM!" : "MONITOR");

  // 节点状态灯
  for (int n = 0; n < MAX_NODES; n++) {
    bool alive = nodes[n].online && (millis() - nodes[n].lastPacketMs) < LINK_TIMEOUT_MS;
    display.fillCircle(678 + n * 14, 68, 3, alive ? NODE_COLS[n % 4] : 0x39E7);
  }
}

/**
 * @brief 节点失联清理：超时未收到数据的节点标记离线并清理目标点
 */
void reapOfflineNodes() {
  if (millis() - lastUptimeMs < 1000) return;
  lastUptimeMs = millis();
  for (int n = 0; n < MAX_NODES; n++) {
    if (nodes[n].online && (millis() - nodes[n].lastPacketMs) > LINK_TIMEOUT_MS) {
      nodes[n].online = false;
      for (int t = 0; t < MAX_TARGETS; t++) {
        targets[n][t].valid = false;
        if (dots[n][t].active) eraseDot(n, t);
      }
      Serial.print("{\"event\":\"node_lost\",\"node\":");
      Serial.print(n + 1);
      Serial.println("}");
    }
  }
}

/* ============================ 蜂鸣器 ============================ */

/**
 * @brief 计算最近有效目标距离（毫米），无目标返回 -1
 */
float closestTargetDistMm() {
  float best = -1.0f;
  for (int n = 0; n < MAX_NODES; n++) {
    for (int t = 0; t < MAX_TARGETS; t++) {
      if (!targets[n][t].valid || staleNow[n][t]) continue;
      float d = sqrtf(targets[n][t].x * targets[n][t].x + targets[n][t].y * targets[n][t].y);
      if (best < 0 || d < best) best = d;
    }
  }
  return best;
}

/**
 * @brief 距离感知蜂鸣：节拍与音调随最近目标距离缩放，警戒时切换告警音
 */
void updateTrackerSound() {
  uint32_t now = millis();

  if (buzzerMuted) {
    if (beepActive) { noTone(BUZZER_PIN); beepActive = false; }
    return;
  }

  if (beepActive && (now - beepStartMs >= BEEP_DUR_MS)) beepActive = false;

  // 警戒告警音：固定高频、快节拍
  if (alarmActive) {
    if (!beepActive && (now - lastBeepMs >= ALARM_INTERVAL_MS)) {
      tone(BUZZER_PIN, ALARM_FREQ, BEEP_DUR_MS);
      beepActive  = true;
      beepStartMs = now;
      lastBeepMs  = now;
    }
    return;
  }

  float dist = closestTargetDistMm();
  if (dist < 0) return;

  float d = constrain(dist, BEEP_DIST_MIN, BEEP_DIST_MAX);
  float t = (d - BEEP_DIST_MIN) / (BEEP_DIST_MAX - BEEP_DIST_MIN);

  uint16_t interval = BEEP_INTERVAL_MIN + (uint16_t)(t * (BEEP_INTERVAL_MAX - BEEP_INTERVAL_MIN));
  uint16_t freq     = BEEP_FREQ_MAX - (uint16_t)(t * (BEEP_FREQ_MAX - BEEP_FREQ_MIN));

  if (!beepActive && (now - lastBeepMs >= interval)) {
    tone(BUZZER_PIN, freq, BEEP_DUR_MS);
    beepActive  = true;
    beepStartMs = now;
    lastBeepMs  = now;
  }
}

/* ============================ 触摸控制 ============================ */

/**
 * @brief 绘制静音按钮
 */
void drawMuteButton() {
  uint16_t border = buzzerMuted ? C_RED : C_GREEN;
  uint16_t fill   = buzzerMuted ? 0x4000 : 0x0320;
  display.fillRect(BTN_X, BTN_Y, BTN_W, BTN_H, fill);
  display.drawRect(BTN_X, BTN_Y, BTN_W, BTN_H, border);
  display.setTextColor(border); display.setTextSize(1);
  display.setCursor(BTN_X + 14, BTN_Y + 16);
  display.print(buzzerMuted ? "STUMM" : "BUZZER AN");
}

/**
 * @brief 触摸检测（边缘触发 + 消抖）：仅当从"未按下"变为"按下"时切换静音
 */
void checkTouch() {
  uint8_t contacts;
  GDTpoint_t points[5];
  contacts = touch.getTouchPoints(points);

  bool touchingButton = false;
  for (uint8_t i = 0; i < contacts; i++) {
    // 触摸原始坐标（竖屏 480x800）映射到横屏 (800x480)
    int16_t tx = points[i].y;
    int16_t ty = 480 - points[i].x;
    if (tx >= BTN_X && tx <= BTN_X + BTN_W && ty >= BTN_Y && ty <= BTN_Y + BTN_H) {
      touchingButton = true;
      break;
    }
  }

  if (touchingButton && !touchDownLast && (millis() - lastToggleMs > 300)) {
    buzzerMuted = !buzzerMuted;
    lastToggleMs = millis();
    drawMuteButton();
  }
  touchDownLast = touchingButton;
}

/* ============================ 网络初始化 ============================ */

void startAP() {
  Serial.print("[NET] 启动热点 '");
  Serial.print(AP_SSID);
  Serial.println("'...");
  WiFi.beginAP(AP_SSID, AP_PASS, 6);
  delay(5000);
  Serial.print("[NET] AP IP: ");
  Serial.println(WiFi.localIP());
  delay(1000);
  udp.begin(UDP_PORT);
  Serial.print("[NET] UDP 监听端口 ");
  Serial.println(UDP_PORT);
}

/* ============================ 周期背景刷新 ============================ */

void refreshBackground() {
  drawBackground();
  drawMuteButton();
  for (int n = 0; n < MAX_NODES; n++)
    for (int t = 0; t < MAX_TARGETS; t++) {
      dots[n][t].active = false;
      if (targets[n][t].valid) drawDot(n, t);
    }
}

/* ============================ 初始化 ============================ */
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
void loop() {
  receiveUdp();
  updateDots();
  reapOfflineNodes();
  updateTrackerSound();
  checkTouch();

  if (millis() - lastBgRefreshMs >= BG_REFRESH_INTERVAL_MS) {
    lastBgRefreshMs = millis();
    refreshBackground();
  }
}

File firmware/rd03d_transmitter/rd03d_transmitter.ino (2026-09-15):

/*
 * ============================================================================
 *  无线毫米波雷达智能感知系统 V1.0 —— 雷达节点发射端固件
 *  Wireless mmWave Radar Smart System - Radar Node Transmitter Firmware
 * ============================================================================
 *  硬件平台  : Seeed Studio XIAO ESP32-S3
 *  雷达模块  : Ai-Thinker RD-03D（24GHz 毫米波雷达，多目标追踪，最大 3 目标）
 *  功能概述  :
 *    1. 通过 UART1 读取 RD-03D 雷达数据帧（波特率 256000）
 *    2. 解析帧头 AA FF 03 00 + 26 字节载荷 + 尾部 55 CC 校验
 *    3. 目标聚类融合（距离小于阈值的目标合并，消除同一人体的多点噪点）
 *    4. 通过 UDP 将目标数据无线传输至接收端（网关/显示节点）
 *    5. 节点心跳与状态上报，支持多节点组网（通过 NODE_ID 区分）
 *    6. 断线自动重连（指数退避），雷达命令周期重发保持多目标模式
 *  网络参数  : 默认 SSID=RadarNet / 密码=radar12345 / UDP 端口=4210
 *  引脚连接  : 雷达 TX -> D0(GPIO1)=UART1_RX | 雷达 RX -> D1(GPIO2)=UART1_TX
 *  注意      : D6/D7(GPIO43/44) 为 USB-Serial(UART0)，不可用作雷达 UART
 *  参考来源  : Arduino-ESP32-Radarproject (MIT License, Copyright (c) 2026 Sudo_solder)
 *              本固件在 MIT 许可下深度重构并增强功能。
 * ============================================================================
 *  MIT License - 详见项目根目录 LICENSE
 * ============================================================================
 */

#include <WiFi.h>
#include <WiFiUdp.h>

/* ============================ 集中配置区 ============================ */
// ---- 网络配置 ----
#define WIFI_SSID          "RadarNet"      // 接收端热点 SSID（编译期可修改）
#define WIFI_PASSWORD      "radar12345"   // 接收端热点密码
#define UDP_PORT           4210           // UDP 端口（与接收端一致）
#define NETWORK_TIMEOUT_SEC 20            // 连接超时（秒）

// ---- 节点标识 ----
#define NODE_ID            0x0001         // 节点编号（多节点组网时逐一递增）
#define NODE_NAME          "NODE-01"      // 节点名称（用于调试输出）

// ---- 雷达串口配置 ----
#define RADAR_UART_NUM     1              // 使用 UART1
#define RADAR_RX_PIN       1              // D0 = GPIO1
#define RADAR_TX_PIN       2              // D1 = GPIO2
#define RADAR_BAUD         256000         // RD-03D 数据波特率
#define RADAR_DIST_MAX_MM  8000           // 最大有效探测距离（毫米）
#define RADAR_DIST_MIN_MM  100            // 最小有效探测距离（毫米，滤除近距杂波）

// ---- 目标聚类参数 ----
#define CLUSTER_DIST_MM    1000.0f        // 聚类距离阈值：小于该距离的多个目标合并
#define MAX_TARGETS        3              // 最大目标数（RD-03D 硬件能力）

// ---- 心跳与命令周期 ----
#define HEARTBEAT_INTERVAL_MS   2000      // 无目标时的心跳间隔（毫秒）
#define CMD_RESEND_INTERVAL_MS  60000     // 多目标命令重发周期（毫秒）
#define WIFI_CHECK_INTERVAL_MS  5000      // WiFi 状态巡检周期（毫秒）

/* ============================ 数据结构 ============================ */

// 单个目标（RD-03D 坐标系：x 为横向偏移，y 为纵向距离，单位毫米）
struct Target {
  int16_t x;       // X 坐标（毫米，正值向右）
  int16_t y;       // Y 坐标（毫米，正值向前）
  int16_t spd;     // 速度（毫米/秒，绝对值表示速率）
  uint8_t valid;   // 有效性标记
};

// 无线传输数据包（固定结构，与接收端保持一致）
struct __attribute__((packed)) UdpPacket {
  uint32_t magic;       // 协议魔数 0xD03DA7A，用于接收端校验
  uint32_t nodeId;      // 节点编号（组网标识）
  uint32_t frameCount;  // 数据帧计数（自启动起递增）
  uint32_t uptimeMs;    // 节点运行时间（毫秒）
  Target   targets[MAX_TARGETS];  // 最多 3 个目标
  uint8_t  flags;       // 状态位：bit0=节点在线心跳
  uint8_t  reserved[3]; // 预留
};

/* ============================ 雷达协议常量 ============================ */

// RD-03D 官方指令（帧头 0xFD 0xFC 0xFB 0xFA + 长度 + 数据 + 校验）
static const uint8_t CMD_ENABLE[14] = {0xFD, 0xFC, 0xFB, 0xFA, 0x04, 0x00, 0xFF, 0x00, 0x01, 0x00, 0x04, 0x03, 0x02, 0x01};
static const uint8_t CMD_MULTI[12]  = {0xFD, 0xFC, 0xFB, 0xFA, 0x02, 0x00, 0x90, 0x00, 0x04, 0x03, 0x02, 0x01};
static const uint8_t CMD_END[12]    = {0xFD, 0xFC, 0xFB, 0xFA, 0x02, 0x00, 0xFE, 0x00, 0x04, 0x03, 0x02, 0x01};

// 数据帧头 4 字节
static const uint8_t HDR[4]         = {0xAA, 0xFF, 0x03, 0x00};

// 数据帧载荷长度与尾部校验
#define FRAME_PAYLOAD_LEN  26
#define FRAME_TAIL_0       0x55
#define FRAME_TAIL_1       0xCC

/* ============================ 全局变量 ============================ */

HardwareSerial RadarSerial(RADAR_UART_NUM);
WiFiUDP        udp;
UdpPacket      pkt;

uint32_t frameCount  = 0;   // 已发送数据帧计数
uint32_t badCount    = 0;   // 校验失败帧计数
uint32_t byteCount   = 0;   // 雷达串口累计字节数
uint32_t lastCmdMs   = 0;   // 上次重发指令时间
uint32_t lastCheckMs = 0;   // 上次 WiFi 巡检时间
uint32_t lastDebugMs = 0;   // 上次调试输出时间
uint32_t lastUdpMs   = 0;   // 上次 UDP 发送时间

// 帧解析状态机
uint8_t  pl[FRAME_PAYLOAD_LEN];
uint8_t  plIdx  = 0;
uint8_t  hdrIdx = 0;
bool     inFrame = false;

IPAddress gatewayIP;        // 接收端（网关）IP
bool     gatewayResolved = false;

/* ============================ 工具函数 ============================ */

/**
 * @brief 解析 RD-03D 原始字节为有符号 16 位整型
 *        采用标准二进制补码解释：0x0000~0x7FFF 为正，0x8000~0xFFFF 为负
 * @param lo 低字节
 * @param hi 高字节
 * @return 有符号坐标值
 */
int16_t decodeSigned(uint8_t lo, uint8_t hi) {
  uint16_t raw = (uint16_t)lo | ((uint16_t)hi << 8);
  if (raw & 0x8000) return (int16_t)(raw | 0xFFFF0000); // 符号扩展为负数
  return (int16_t)raw;
}

/**
 * @brief 目标聚类融合：将同一传感器上报的、物理距离小于阈值的多个目标合并
 *        为单个目标（消除同一人体的躯干+四肢多噪点），取坐标中点并保留较大速度
 */
void clusterTargets() {
  for (int i = 0; i < MAX_TARGETS; i++) {
    if (!pkt.targets[i].valid) continue;
    for (int j = i + 1; j < MAX_TARGETS; j++) {
      if (!pkt.targets[j].valid) continue;
      float dx = (float)pkt.targets[i].x - (float)pkt.targets[j].x;
      float dy = (float)pkt.targets[i].y - (float)pkt.targets[j].y;
      float dist = sqrtf(dx * dx + dy * dy);
      if (dist < CLUSTER_DIST_MM) {
        // 合并：取坐标中点，速度取较大者
        pkt.targets[i].x   = (int16_t)(((float)pkt.targets[i].x + (float)pkt.targets[j].x) / 2.0f);
        pkt.targets[i].y   = (int16_t)(((float)pkt.targets[i].y + (float)pkt.targets[j].y) / 2.0f);
        pkt.targets[i].spd = (int16_t)fmaxf((float)pkt.targets[i].spd, (float)pkt.targets[j].spd);
        pkt.targets[j] = {0, 0, 0, 0};
      }
    }
  }
}

/**
 * @brief 解析雷达帧载荷并构建 UDP 数据包发送至接收端
 * @param pl 帧载荷（26 字节）
 * 载荷布局：目标1(8B) + 目标2(8B) + 目标3(8B) + 尾部(2B: 0x55 0xCC)
 * 每目标 8B：x(2B) y(2B) spd(2B) 预留(2B)
 */
void parseAndSend(const uint8_t *pl) {
  for (int i = 0; i < MAX_TARGETS; i++) {
    const uint8_t *b = pl + i * 8;

    // 目标是否为空（全零判定）
    bool empty = true;
    for (int j = 0; j < 8; j++) { if (b[j]) { empty = false; break; } }
    if (empty) { pkt.targets[i] = {0, 0, 0, 0}; continue; }

    // 解码坐标与速度
    int16_t xi  = decodeSigned(b[0], b[1]);
    int16_t yi  = decodeSigned(b[2], b[3]);
    int16_t spi = decodeSigned(b[4], b[5]);

    // 距离过滤：剔除近距杂波（<100mm）与超距噪声（>8000mm）
    float dist = sqrtf((float)xi * xi + (float)yi * yi);
    if (dist > RADAR_DIST_MIN_MM && dist <= RADAR_DIST_MAX_MM) {
      pkt.targets[i] = {xi, yi, spi, 1};
    } else {
      pkt.targets[i] = {0, 0, 0, 0};
    }
  }

  // 聚类融合
  clusterTargets();

  // 帧计数自增，发送数据包
  pkt.frameCount = ++frameCount;
  pkt.uptimeMs   = millis();
  pkt.nodeState  = 0x01;
  lastUdpMs      = millis();

  if (gatewayResolved) {
    udp.beginPacket(gatewayIP, UDP_PORT);
    udp.write((uint8_t*)&pkt, sizeof(pkt));
    udp.endPacket();
  }
}
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
